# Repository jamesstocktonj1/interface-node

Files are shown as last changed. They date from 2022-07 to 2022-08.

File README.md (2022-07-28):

# Garden Interface Node

## Hardware
The hardware is based around the Pi Pico. It simply has 2x RS485 interfaces to independent Serial ports. It also has a range of status LEDs to do with flow control and the bus status.

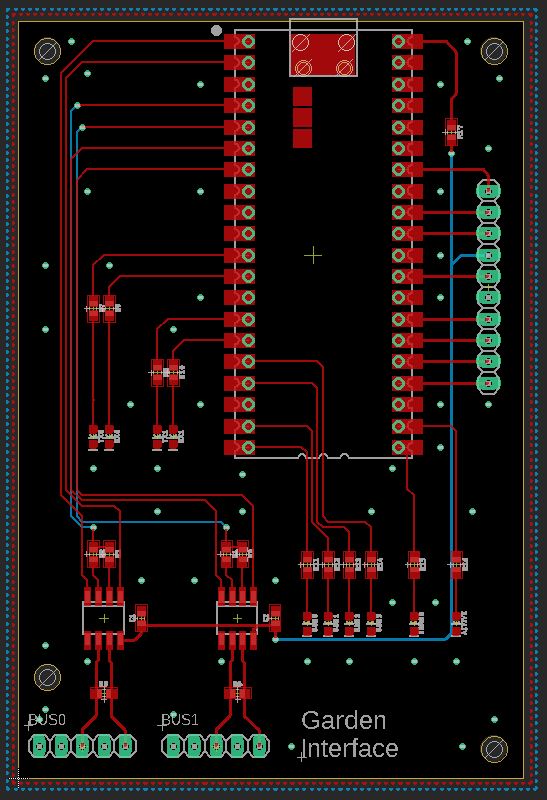
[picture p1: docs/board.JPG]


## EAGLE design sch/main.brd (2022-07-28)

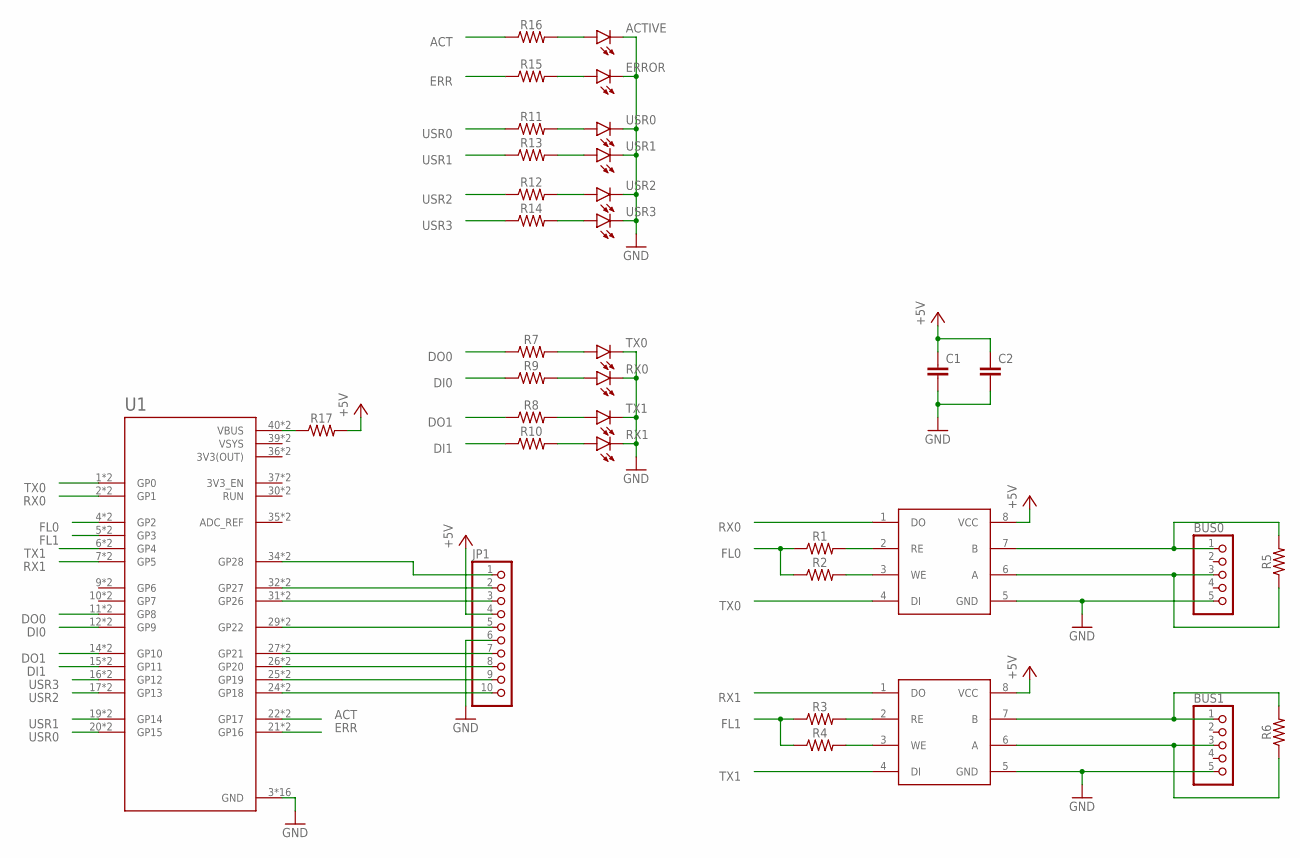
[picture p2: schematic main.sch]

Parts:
ACTIVE: LED0603; LED-0603
BUS0, BUS1: PINHD-1X5; 1X05
C1, C2: CAP-0603; 0603
ERROR: LED0603; LED-0603
JP1: PINHD-1X10; 1X10
R1, R2, R3, R4, R5, R6, R7, R8, R9, R10, R11, R12, R13, R14, R15, R16, R17: 0603
RX0, RX1: LED0603; LED-0603
TX0, TX1: LED0603; LED-0603
U1: RASPBERRY_PICO-NO_DEBUG; PICO-PKG-NO_DEBUG
U$1, U$2: MAX485; SO8
USR0, USR1, USR2, USR3: LED0603; LED-0603

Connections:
3V3(OUT): U1.36 (3V3(OUT)), U1.P$36 (3V3(OUT))
+5V: C1.1, C2.1, JP1.4, R17.2, U$1.8 (VCC), U$2.8 (VCC)
ACT: R16.1, U1.22 (GP17), U1.P$22 (GP17)
DI0: R9.1, U1.12 (GP9), U1.P$12 (GP9)
DI1: R10.1, U1.15 (GP11), U1.P$15 (GP11)
DO0: R7.1, U1.11 (GP8), U1.P$11 (GP8)
DO1: R8.1, U1.14 (GP10), U1.P$14 (GP10)
ERR: R15.1, U1.21 (GP16), U1.P$21 (GP16)
FL0: R1.1, R2.1, U1.4 (GP2), U1.P$4 (GP2)
FL1: R3.1, R4.1, U1.5 (GP3), U1.P$5 (GP3)
GND: ACTIVE.C, BUS0.5, BUS1.5, C1.2, C2.2, ERROR.C, JP1.6, RX0.C, RX1.C, TX0.C, TX1.C, U1.3 (GND), U1.8 (GND), U1.13 (GND), U1.18 (GND), U1.23 (GND), U1.28 (GND), U1.33 (GND), U1.38 (GND), U1.P$3 (GND), U1.P$8 (GND), U1.P$13 (GND), U1.P$18 (GND), U1.P$23 (GND), U1.P$28 (GND), U1.P$33 (GND), U1.P$38 (GND), U$1.5 (GND), U$2.5 (GND), USR0.C, USR1.C, USR2.C, USR3.C
unnamed: BUS0.1, R5.2, U$1.7 (B)
unnamed: BUS0.3, R5.1, U$1.6 (A)
unnamed: BUS1.1, R6.2, U$2.7 (B)
unnamed: BUS1.3, R6.1, U$2.6 (A)
unnamed: R1.2, U$1.2 (RE)
unnamed: R2.2, U$1.3 (WE)
unnamed: R3.2, U$2.2 (RE)
unnamed: R4.2, U$2.3 (WE)
unnamed: R11.2, USR0.A
unnamed: R7.2, TX0.A
unnamed: R9.2, RX0.A
unnamed: R8.2, TX1.A
unnamed: R10.2, RX1.A
unnamed: R13.2, USR1.A
unnamed: R12.2, USR2.A
unnamed: R14.2, USR3.A
unnamed: ERROR.A, R15.2
unnamed: ACTIVE.A, R16.2
unnamed: JP1.10, U1.24 (GP18), U1.P$24 (GP18)
unnamed: JP1.9, U1.25 (GP19), U1.P$25 (GP19)
unnamed: JP1.8, U1.26 (GP20), U1.P$26 (GP20)
unnamed: JP1.7, U1.27 (GP21), U1.P$27 (GP21)
unnamed: JP1.5, U1.29 (GP22), U1.P$29 (GP22)
unnamed: JP1.3, U1.31 (GP26), U1.P$31 (GP26)
unnamed: JP1.2, U1.32 (GP27), U1.P$32 (GP27)
unnamed: JP1.1, U1.34 (GP28), U1.P$34 (GP28)
unnamed: R17.1, U1.40 (VBUS), U1.P$40 (VBUS)
RX0: U1.2 (GP1), U1.P$2 (GP1), U$1.1 (DO)
RX1: U1.7 (GP5), U1.P$7 (GP5), U$2.1 (DO)
TX0: U1.1 (GP0), U1.P$1 (GP0), U$1.4 (DI)
TX1: U1.6 (GP4), U1.P$6 (GP4), U$2.4 (DI)
USR0: R11.1, U1.20 (GP15), U1.P$20 (GP15)
USR1: R13.1, U1.19 (GP14), U1.P$19 (GP14)
USR2: R12.1, U1.17 (GP13), U1.P$17 (GP13)
USR3: R14.1, U1.16 (GP12), U1.P$16 (GP12)
VSYS: U1.39 (VSYS), U1.P$39 (VSYS)

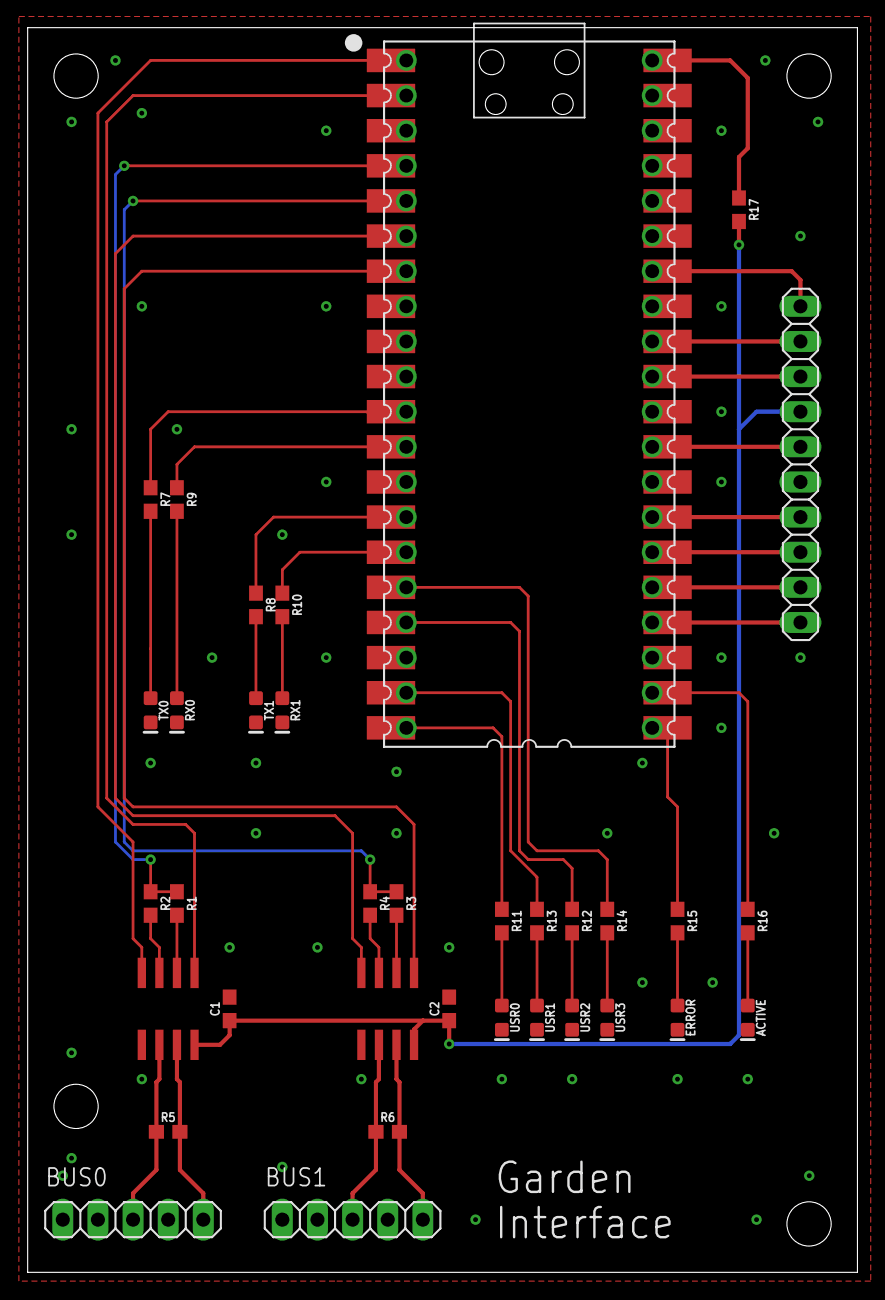
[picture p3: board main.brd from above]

Board: 2 copper layers, 60.0 x 90.0 mm, 35 parts (0 on the bottom side), 47 nets.

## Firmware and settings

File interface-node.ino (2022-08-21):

#include "pins.h"
#include "comms.h"



void init_pins(void);
void set_pins(void);
void reset_leds(void);
void set_flow1(uint8_t state);
void set_flow2(uint8_t state);

void init_serial(void);
void timeout_reply(void);

void init_timer(void);
void reset_timer(void);

void parse_usb_serial(char c);
void parse_serial(char c);


enum {
  COM_WAIT,
  COM_START,
  COM_MID,
  COM_REPLY,
  COM_END,
  COM_ACK,
  COM_NAK,
  COM_TIMEOUT
} comm_state;

//uint8_t comms_state;
uint8_t input_buffer;
uint16_t timer1;



void setup() {

  init_pins();
  init_serial();
  init_timer();

  comm_state = COM_WAIT;
}

void loop() {

  while(Serial.available()) {
    parse_usb_serial(Serial.read());
  }

  while(Serial1.available()) {
    parse_serial(Serial1.read());
  }

  while(Serial2.available()) {
    parse_serial(Serial2.read());
  }

  if(timer1 == 0) {

    set_flow1(TRANSMIT);
    set_flow2(TRANSMIT);

    if(comm_state == COM_END) {
      comm_state = COM_TIMEOUT;
      timeout_reply();
    }
    else if(comm_state != COM_WAIT) {
      comm_state = COM_WAIT;
      reset_leds();
    }
  }
}

void setup1() {}

void loop1() {

  if (timer1) {
    timer1--;
  }
  
  set_pins();

  delay(1);
}



void init_pins() {

  pinMode(TXLED1, OUTPUT);
  pinMode(RXLED1, OUTPUT);
  pinMode(TXLED2, OUTPUT);
  pinMode(RXLED2, OUTPUT);

  pinMode(USR0, OUTPUT);
  pinMode(USR1, OUTPUT);
  pinMode(USR2, OUTPUT);
  pinMode(USR3, OUTPUT);

  pinMode(ACT, OUTPUT);
  pinMode(ERR, OUTPUT);
  digitalWrite(ACT, LOW);
  digitalWrite(ERR, LOW);
}

void set_pins() {
  uint8_t state = 0;

  switch (comm_state) {
    case COM_WAIT:
      break;
    case COM_START:
      state = (1 << 2);
      break;
    case COM_MID:
    case COM_END:
      state = (1 << 2) | (1 << 3);
      break;

    case COM_REPLY:
      state = (1 << 3);
      break;
    case COM_ACK:
      state = (1 << 3);
      break;
    case COM_NAK:
      state = (1 << 3) | (1 << 1);
      break;
    case COM_TIMEOUT:
      state = (1 << 0);
      break;
  }

  if (state) {

    digitalWrite(USR0, state & (1 << 0));
    digitalWrite(USR1, state & (1 << 1));
    digitalWrite(USR2, state & (1 << 2));
    digitalWrite(USR3, state & (1 << 3));

    digitalWrite(ERR, state & 0x3);
  }
  digitalWrite(ACT, timer1);
}

void reset_leds() {

  digitalWrite(USR0, LOW);
  digitalWrite(USR1, LOW);
  digitalWrite(USR2, LOW);
  digitalWrite(USR3, LOW);

  digitalWrite(ACT, LOW);
  digitalWrite(ERR, LOW);
}


void init_serial() {

  pinMode(FL1, OUTPUT);
  pinMode(FL2, OUTPUT);
  digitalWrite(FL1, HIGH);
  digitalWrite(FL2, HIGH);

  Serial1.setTX(TX1);
  Serial1.setRX(RX1);
  set_flow1(TRANSMIT);

  Serial2.setTX(TX2);
  Serial2.setRX(RX2);
  set_flow2(TRANSMIT);

  Serial1.begin(9600);
  Serial2.begin(9600);
  Serial.begin();
}

void timeout_reply() {

  Serial.write("RTE\n");
}

void set_flow1(uint8_t state) {

  digitalWrite(FL1, state);

  digitalWrite(TXLED1, state);
  digitalWrite(RXLED1, !state);
}

void set_flow2(uint8_t state) {

  digitalWrite(FL2, state);

  digitalWrite(TXLED2, state);
  digitalWrite(RXLED2, !state);
}


void init_timer() {

  timer1 = 0;
}

void reset_timer() {

  timer1 = COMMS_TIMEOUT;
}


void parse_usb_serial(char c) {
  reset_timer();
  
  Serial.write(c);
  Serial1.write(c);
  Serial2.write(c);

  if(c == SEND_START_CHAR) {
    comm_state = COM_START;
  }
  else if (c == END_CHAR) {
    comm_state = COM_END;
    
    Serial1.flush();
    Serial2.flush();
    
    delay(TX_DELAY);
    set_flow1(RECEIVE);
    set_flow2(RECEIVE);
  }
  else {
    comm_state = COM_MID;
  }
}

void parse_serial(char c) {
  reset_timer();

  Serial.write(c);

  if(c == REPLY_START_CHAR) {
    comm_state = COM_REPLY;
  }
  else if(c == REPLY_ACK) {
    comm_state = COM_ACK;
  }
  else if(c == REPLY_NACK) {
    comm_state = COM_NAK;
  }
  else if(c == END_CHAR) {
    comm_state = COM_WAIT;
    
    set_flow1(TRANSMIT);
    set_flow2(TRANSMIT);

    Serial.flush();
    Serial.write("\n");
  }
}

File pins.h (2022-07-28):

// pin definition file


// Interface 1
#define TX1         0
#define RX1         1
#define FL1         2

// Interface 2
#define TX2         4
#define RX2         5
#define FL2         3

// Interface LEDs
#define TXLED1      8
#define RXLED1      9
#define TXLED2      10
#define RXLED2      11

// User LEDs
#define USR0        15
#define USR1        14
#define USR2        13
#define USR3        12
int user_led[4] =   {USR0, USR1, USR2, USR3};

// Activity LEDs
#define ACT         17
#define ERR         16

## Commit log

2022-07-28 Add Board Files
    [main.brd, main.sch]
2022-07-30 Add State Based Flow Control
2022-07-30 Fix Flow Control
2022-07-30 Add Led Reset on Timeout
    [interface-node.ino]
2022-07-30 Add Status LED
2022-07-30 Fix Status LED
2022-08-21 Fix Clear Write Buffer / Refactor
    [interface-node.ino]

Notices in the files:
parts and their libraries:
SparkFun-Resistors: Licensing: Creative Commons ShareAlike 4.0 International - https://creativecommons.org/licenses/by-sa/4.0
